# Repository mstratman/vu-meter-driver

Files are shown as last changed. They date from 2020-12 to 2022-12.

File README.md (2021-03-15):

# VU Meter driver board

Most VU meters these days are actually DC meters, so they need a rectifier. And if you're going to use them you typically want a buffer to prevent noise, too.  This PCB provides both, along with adjustable gain, and is a dead quiet, simple drop-in for any pedal and should work with any DC meter.

It provides a decorative dancing needle to your audio projects, but understand this isn't an ideal way to take measurements if accuracy is your goal.

You can get the meters dirt cheap, and scavenge them from battery testers, CB testers, and other old junk.  You can also find plenty for sale new by searching "*DC needle meter*" or similar search terms.

[Buy VU meter PCB here](https://shop.mas-effects.com/products/vu-meter-driver) or use the files in this repository to create your own.

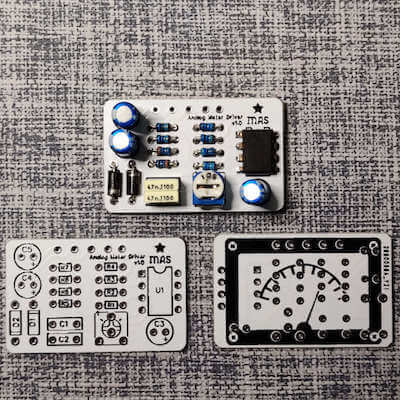
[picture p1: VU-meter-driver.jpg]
VU meter driver (https://shop.mas-effects.com/products/vu-meter-driver)

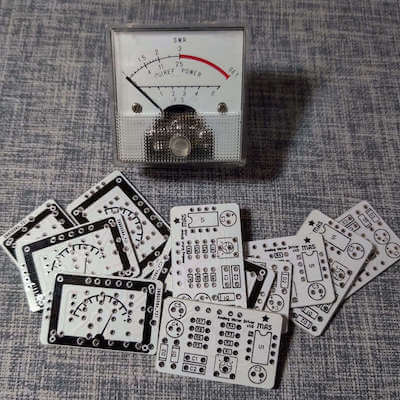
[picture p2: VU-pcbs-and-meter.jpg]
VU meter driver PCBs (https://shop.mas-effects.com/products/vu-meter-driver)

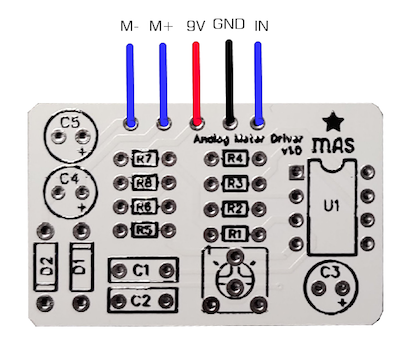
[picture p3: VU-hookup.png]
VU meter driver hookup (https://shop.mas-effects.com/products/vu-meter-driver)


## Schematic

[Schematic is available here](./VU-driver-1.0-schematic.png)

## Instructions

See the build documents at <https://mas-effects.com/vu.pdf>

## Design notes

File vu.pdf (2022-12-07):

# DC Meter Driver

mas-effects.com/vu-meter-driver/

Most VU meters these days are actually DC meters, so they need a rectifier. And if you're going to use them you typically want a buffer to prevent noise, too. The good news is you can get the meters dirt cheap, and scavenge them from battery testers, CB testers, and other old junk.
This PCB is a dead quiet, simple drop-in for any pedal, and should work with any DC meter.
It powers a decorative dancing needle for your audio projects, but understand this isn't an ideal way to take measurements if accuracy is your goal.

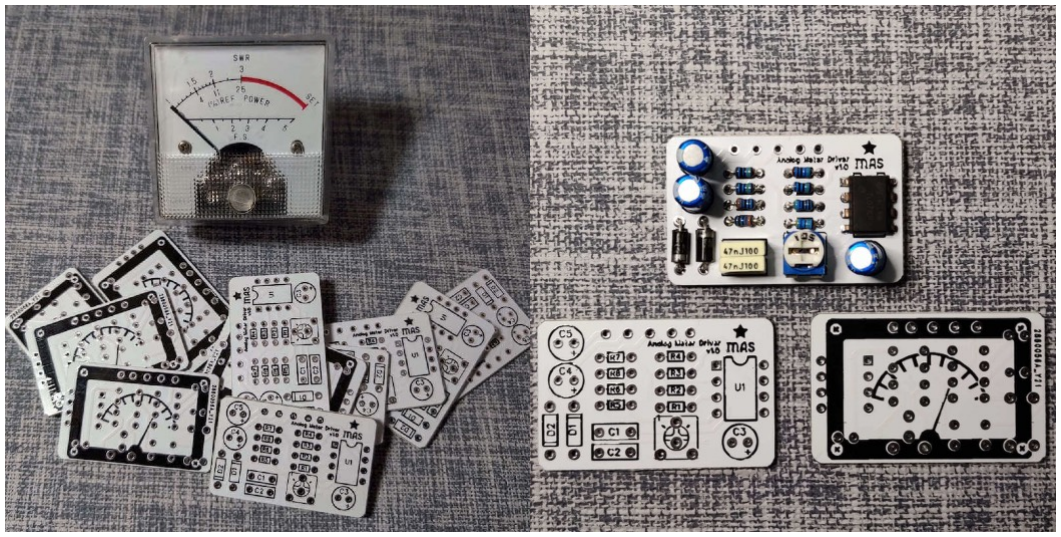
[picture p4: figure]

# Bill of Materials

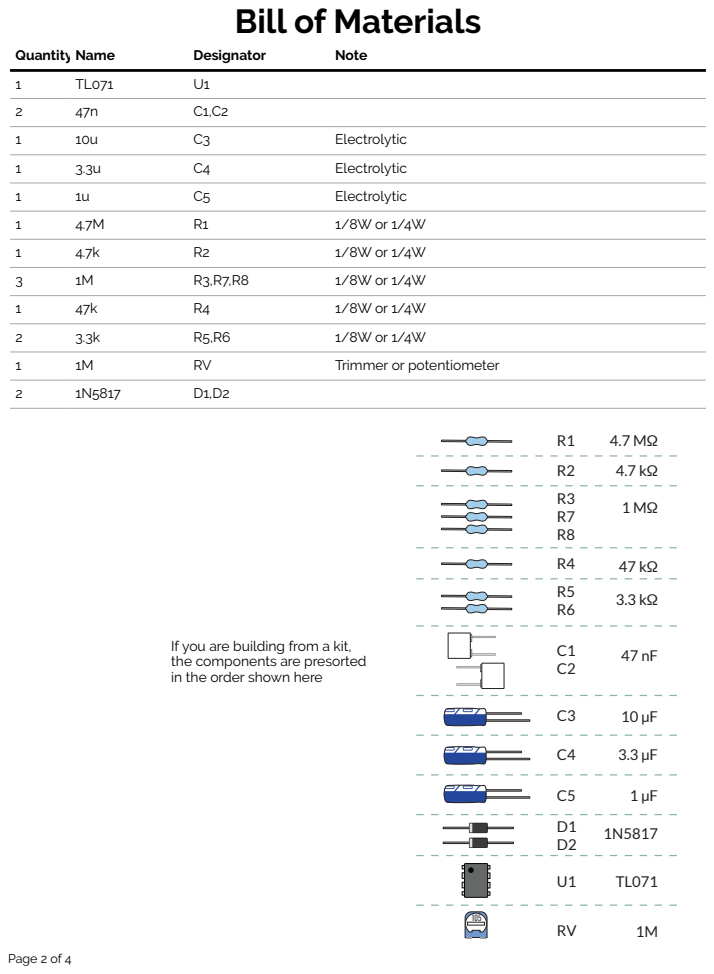
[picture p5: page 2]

1 | TL071 U1
2 | 47n C1,C2

If you are building from a kit,
the components are presorted
in the order shown here

# Schematic

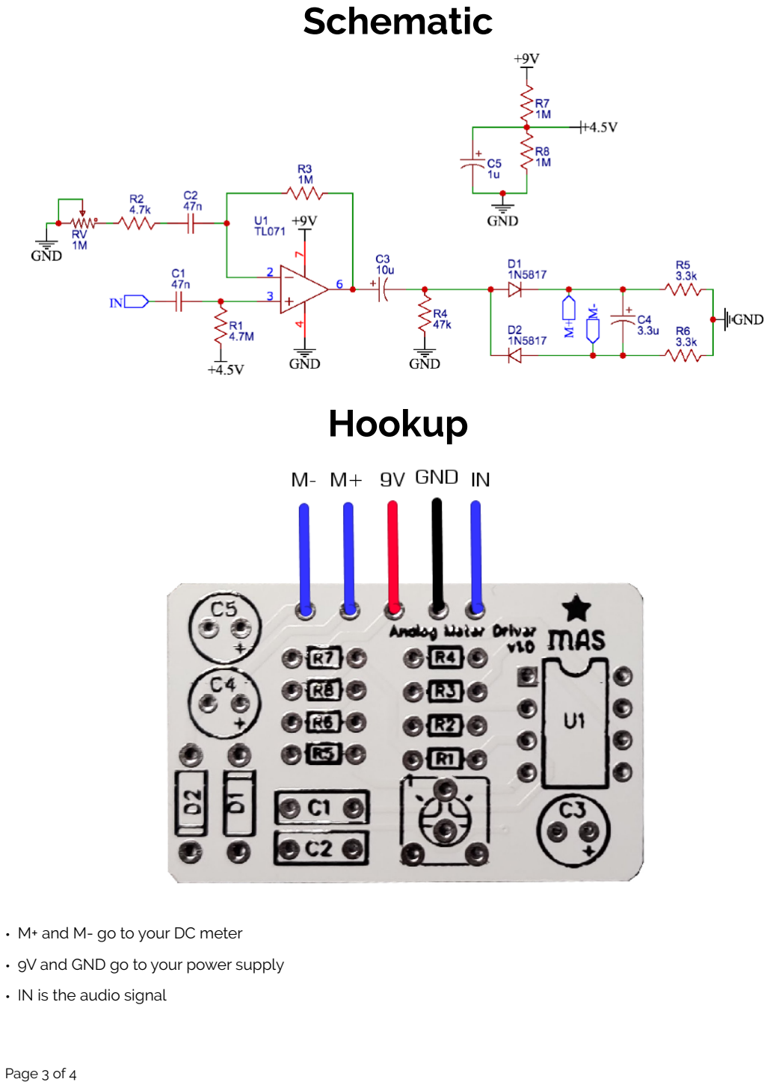
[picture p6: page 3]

# Hookup

- M+ and M- go to your DC meter
- 9V and GND go to your power supply
- IN is the audio signal

# Build Notes

## Level Adjustment

The level can be adjusted using RV. Although the PCB has holes for a trimmer, you can absolutely use an off-board potentiometer, fixed resistor, or even multiple resistors selectable with a toggle switch.
Perhaps not surprisingly, you will find this responds differently to humbuckers and single coil pickups. Having an off-board potentiometer or toggle switch can make it a lot more convenient to use than a trimmer.

## Tap Audio Before or After Effect?

When using this circuit in a guitar effects pedal, you may wonder whether to take the IN signal from your pedal's input or output. i.e. before or after your audio circuit processes the signal.
There's no right answer, and it's simply personal preference.
I actually prefer to use a toggle switch to let the player decide. What's
more, I'll use an ON-OFF-ON switch to allow the middle position to
cut power and audio signal to the meter's PCB, as shown in this illustration:
Taking the IN signal from your audio's PCB IN rather than directly from the input jack ensures this doesn't activate when your effect is bypassed.

## Needle Speed

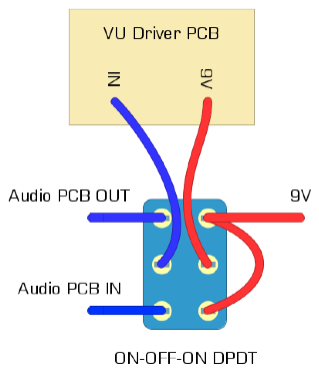
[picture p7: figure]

You can adjust the value of C4 to alter how quickly the needle rises falls back down. 100uF, for example, will slow it down considerably.

## Reducing Bass Responsiveness

By default the low notes will push the needle harder than higher notes. If you want to counteract this you can try decreasing the value of either C2 or C3.
For example, changing C3 to 100nF will tame the needle when strumming heavily on the lower strings.

# Problems? Questions? Share your build!

Visit the MAS Effects forum at reddit.com/r/maseffects/ to post questions, or to showcase your build.

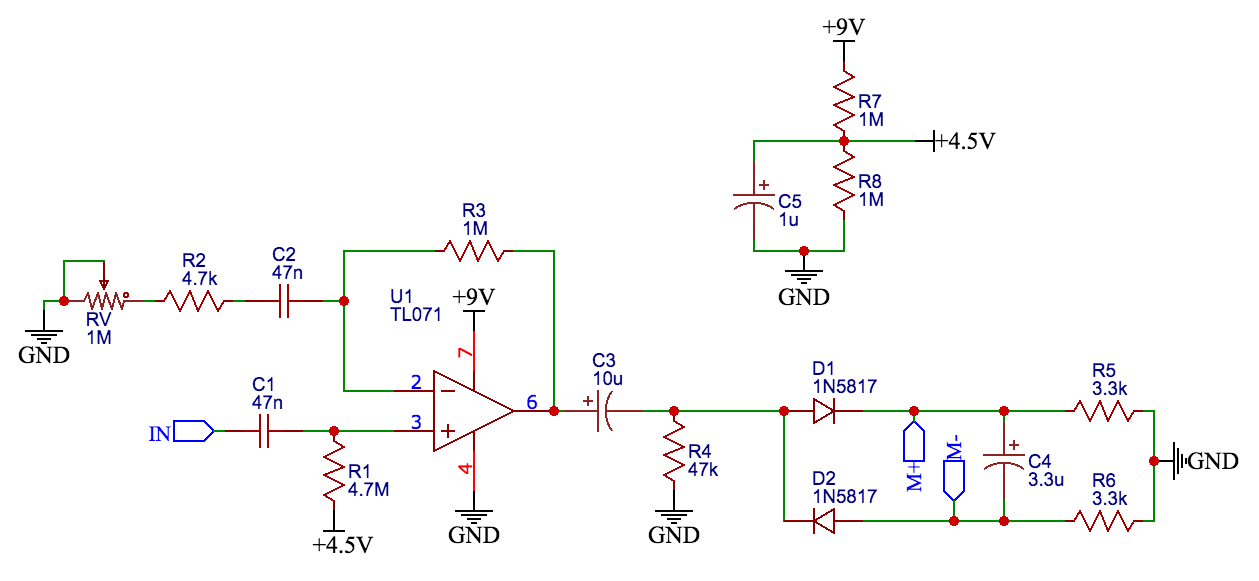
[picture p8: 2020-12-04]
VU-driver-1.0-schematic.png

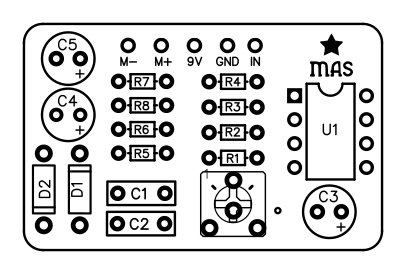
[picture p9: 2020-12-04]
VU-driver-1.0-layout.png

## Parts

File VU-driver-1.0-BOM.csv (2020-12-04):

Designator | Name | Quantity | Notes
U1 | TL071 | 1
C1,C2 | 47n | 2
C3 | 10u | 1 | Electrolytic
C4 | 3.3u | 1 | Electrolytic
C5 | 1u | 1 | Electrolytic
R1 | 4.7M | 1 | 1/8W
R2 | 4.7k | 1 | 1/8W
R3,R7,R8 | 1M | 3 | 1/8W
R4 | 47k | 1 | 1/8W
R5,R6 | 3.3k | 2 | 1/8W
RV | 1M | 1 | Trimmer
D1,D2 | 1N5817 | 2

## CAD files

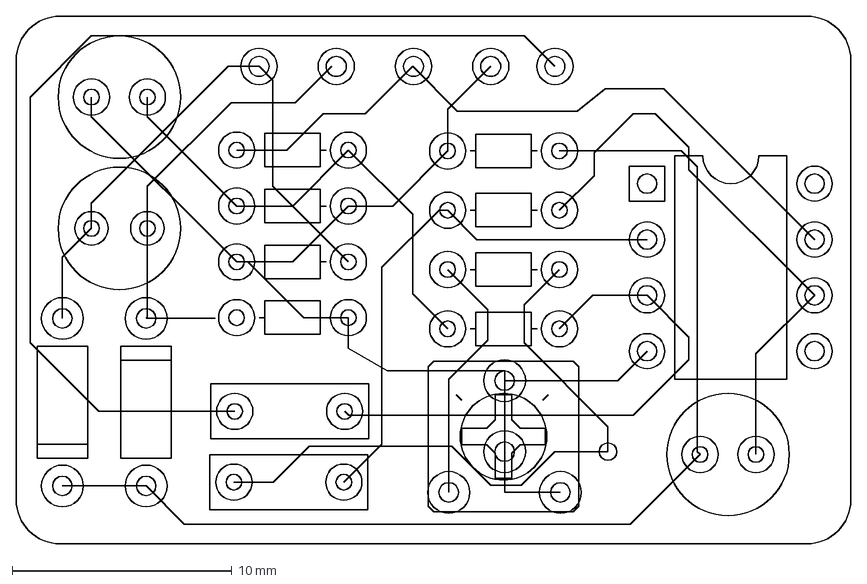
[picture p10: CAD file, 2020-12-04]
VU-driver-1.0.dxf
38.0 x 24.0 mm

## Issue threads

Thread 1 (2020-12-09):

Panel Meter Specs

Andrew-Hanlon, 2020-12-09:
Thanks for the great pedal add on - I have ordered a couple of the kits!

Can you add some additional detail around the required Panel Meter specs? I am assuming it is a DC volt meter, but in what range is usable? Thanks!

mstratman, 2020-12-09:
Yes a DC volt meter. I'm going to guess any meter will work with it.

That said, I'll try to measure or calculate its range later for the values listed in the schematic. However even if you got a meter that was hard to dial in, you can pretty easily switch the gain with component swaps, or change the sensitivity of the RV pot/trimmer.

Andrew-Hanlon, 2020-12-09:
Thanks @mstratman for the information and I would certainly appreciate the additional info for the OOTB sensitivity range.

mstratman, 2020-12-10:
I did a quick and dirty test and was getting it to go up to about 3V.

Andrew-Hanlon, 2020-12-10:
Thanks kindly @mstratman . I guess that makes sense - basically the meter's range should be below the approximate half rail voltage (4.5v) and then adjust the gain to suit. Cheers.

mstratman, 2020-12-10:
Yeah, exactly. To be clear that was with a 9V supply.

Closed 2020-12-10.

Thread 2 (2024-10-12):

Meter doesnt retun to zero.

The4gotn1, 2024-10-12:
Ordered your kit and components.  I finished the build and when powered on the meter is already half way up.  It then moves when I send a signal through it amd returns to half way up.  Only when I pull the power does it return to 0.

Any ideas?

mstratman, 2024-10-12:
Try measuring your voltage at the d1 d2 intersection. Also at the input of the entire board.

Closing since it's not an issue with the project but your build. Happy to continue helping troubleshoot though, but I'll have limited ability until Tues when I'm back in my office

The4gotn1, 2024-10-12:
I get 3.04 v on the D1 leg closest to the edge of the board.  But I get 0 on the D2 leg closest to the edge of the board.

________________________________
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

The4gotn1, 2024-10-12:
Sorry wrong pins. I get .263v on both.

________________________________
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

Closed 2024-10-12.

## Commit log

2021-03-15 add link to schematic so it's easier to find
2024-05-23 added new gerber
